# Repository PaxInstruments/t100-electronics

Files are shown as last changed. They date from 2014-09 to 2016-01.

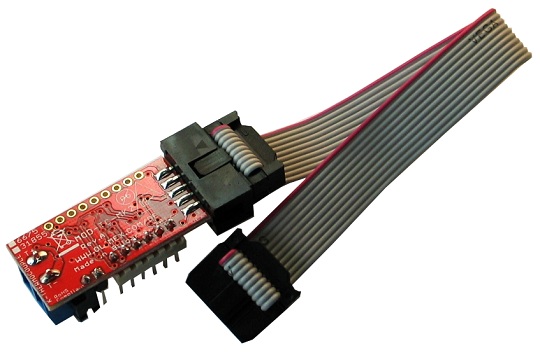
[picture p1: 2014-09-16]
referenceDesigns/Olimex-MOD-TC-MK2-31855-2-photoback.jpg

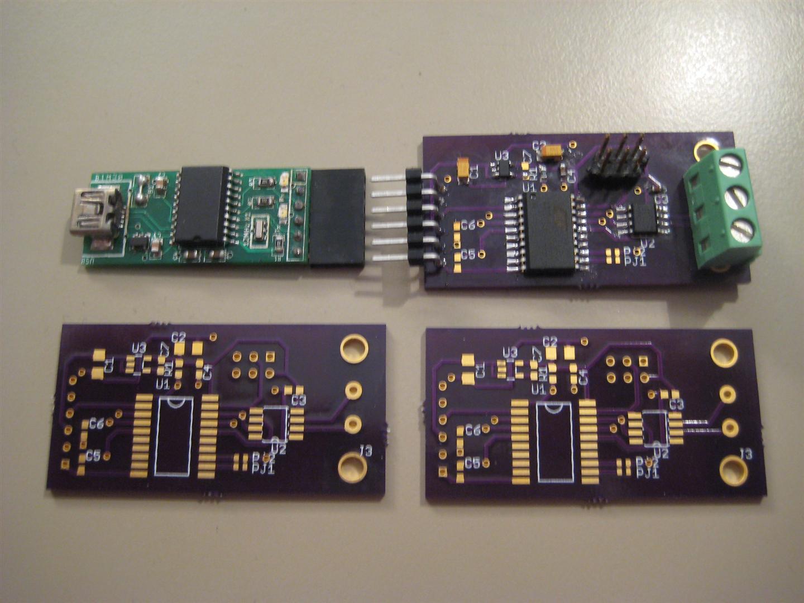
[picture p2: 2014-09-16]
referenceDesigns/SerialCouple-photo.JPG

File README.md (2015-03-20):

# t100-electronics

### Overview
Pax Instruments T100 thermocouple USB adapter.

## T100 Projects

- [Electronics](https://github.com/PaxInstruments/t100-electronics)
- [Enclosure](https://github.com/PaxInstruments/t100-enclosure)
- [Firmware](https://github.com/PaxInstruments/t100-firmware)
- [Software](https://github.com/PaxInstruments/t100-software)

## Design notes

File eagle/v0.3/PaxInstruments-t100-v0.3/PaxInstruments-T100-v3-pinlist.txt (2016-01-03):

Pinlist

Exported from PaxInstruments-T100.brd at 2016-01-03 10:57 

EAGLE Version 6.5.0 Copyright (c) 1988-2013 CadSoft

Part     Pad      Net

C1       1        USB_5V
         2        GND

C2       1        A_5V
         2        AGND

C4       1        A_5V
         2        AGND

C5       1        A_5V
         2        AGND

C6       1        TC-
         2        AGND

C7       1        TC+
         2        AGND

C8       1        TC+
         2        TC-

C9       1        USB_5V
         2        GND

D1       1        N$2
         2        GND

D2       1        N$1
         2        GND

JP2      1        SPARE
         2        USB_5V
         3        SCL
         4        SDA
         5        /RST
         6        GND

JP3      1        GND
         2        SPARE

JP4      D+1      N$1
         D-1      N$2
         GND1     USB_5V
         P$1               *** unconnected ***
         P$3               *** unconnected ***
         VBUS1    GND

LED1     A        N$5
         C        GND

R1       1        D+
         2        N$2

R2       1        D-
         2        N$1

R3       1        AGND
         2        N$3

R4       1        N$4
         2        A_5V

R5       1        TC-
         2        N$3

R6       1        TC+
         2        N$4

R7       1        SDA
         2        USB_5V

R8       1        SCL
         2        USB_5V

R9       1        N$1
         2        USB_5V

R10      1        N$5
         2        SPARE

SJ1      1        A_5V
         2        USB_5V

SJ2      1        GND
         2        AGND

U$1     
U$2      P$1      N$3

U$3      1        TC+
         2        AGND
         3        SCL
         4        SDA
         5        A_5V
         6        TC-

U$4      1        A_5V
         2        AGND
         3                 *** unconnected ***
         4        SCL
         5        SDA

U$6      P$1      N$4

U1       1        /RST
         2        D-
         3        D+
         4        GND
         5        SDA
         6        SPARE
         7        SCL
         8        USB_5V

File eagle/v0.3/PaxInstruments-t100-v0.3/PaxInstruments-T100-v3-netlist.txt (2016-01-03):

Netlist

Exported from PaxInstruments-T100.brd at 2016-01-03 10:57 

EAGLE Version 6.5.0 Copyright (c) 1988-2013 CadSoft

Net      Part     Pad

/RST     JP2      5
         U1       1

AGND     C2       2
         C4       2
         C5       2
         C6       2
         C7       2
         R3       1
         SJ2      2
         U$3      2
         U$4      2

A_5V     C2       1
         C4       1
         C5       1
         R4       2
         SJ1      1
         U$3      5
         U$4      1

D+       R1       1
         U1       3

D-       R2       1
         U1       2

GND      C1       2
         C9       2
         D1       2
         D2       2
         JP2      6
         JP3      1
         JP4      VBUS1
         LED1     C
         SJ2      1
         U1       4

N$1      D2       1
         JP4      D+1
         R2       2
         R9       1

N$2      D1       1
         JP4      D-1
         R1       2

N$3      R3       2
         R5       2
         U$2      P$1

N$4      R4       1
         R6       2
         U$6      P$1

N$5      LED1     A
         R10      1

SCL      JP2      3
         R8       1
         U$3      3
         U$4      4
         U1       7

SDA      JP2      4
         R7       1
         U$3      4
         U$4      5
         U1       5

SPARE    JP2      1
         JP3      2
         R10      2
         U1       6

TC+      C7       1
         C8       1
         R6       1
         U$3      1

TC-      C6       1
         C8       2
         R5       1
         U$3      6

USB_5V   C1       1
         C9       1
         JP2      2
         JP4      GND1
         R7       2
         R8       2
         R9       2
         SJ1      2
         U1       8

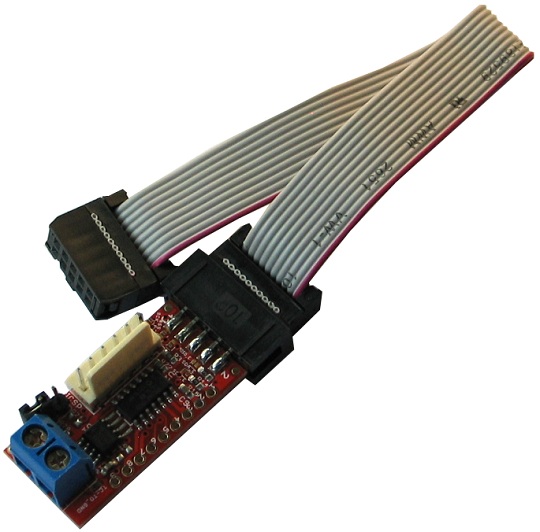
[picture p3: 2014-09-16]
referenceDesigns/Olimex-MOD-TC-MK2-photo-front.jpg

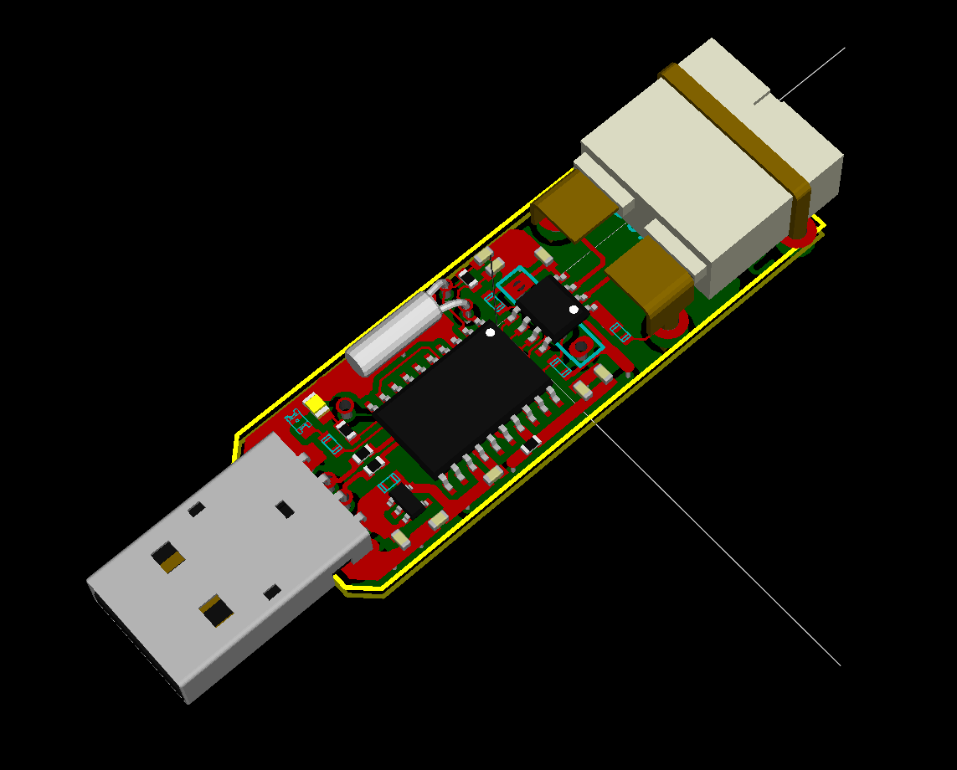
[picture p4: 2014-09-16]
referenceDesigns/GGLabs-ustk01-render.png

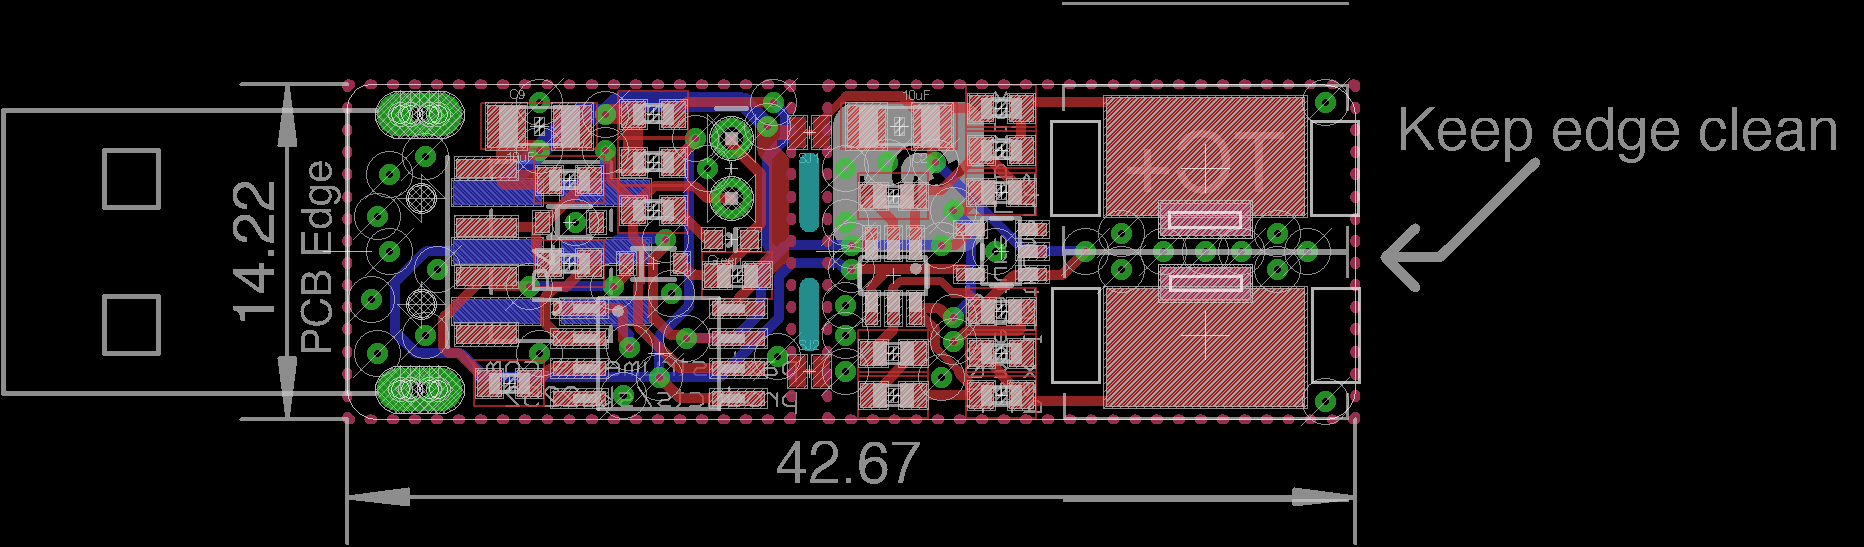
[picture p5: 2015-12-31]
eagle/v0.3/PaxInstruments-t100-v0.3/PaxInstruments-T100-v3-pcb.png

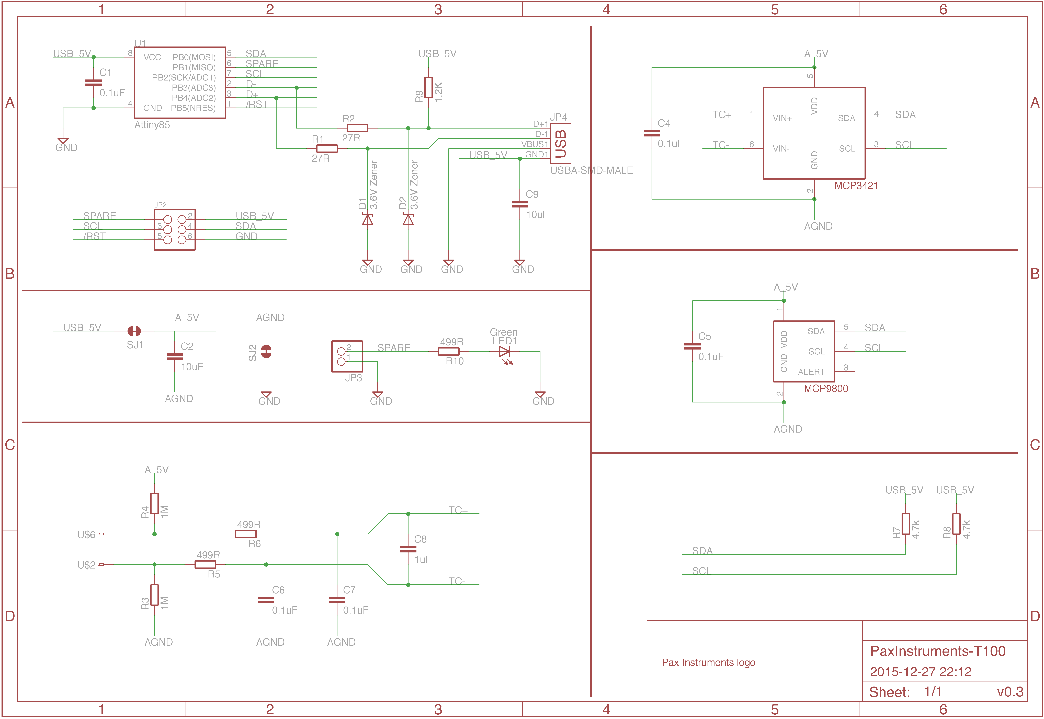
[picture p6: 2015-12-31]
eagle/v0.3/PaxInstruments-t100-v0.3/PaxInstruments-T100-v3-sch.png

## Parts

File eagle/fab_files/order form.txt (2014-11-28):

Board size (板子大小)
45 x 18 mm

Board layers (板子层数)
2

Board quantity (板子数量)
10

Board thickness (板子厚度)
1.6 mm

Minimum line width/spacing (最小线宽/线距)
6/6

Via (过孔)
0.3 mm

Solder mask color (阻焊颜色)
Blue (蓝色)

Character color (字符颜色)
White (白色)

Pad spraying (焊盘喷镀)
Immersion Gold (沉金)

Solder coverage (阻焊覆盖)
Through-hole cover oil (过孔盖油)

Flying probe test (飞针测试)
Visual (目测)

Copper thickness (铜箔厚度)
1 oz

Delivery time (发货时间)
48 hour expedited service (48小时加急服务)

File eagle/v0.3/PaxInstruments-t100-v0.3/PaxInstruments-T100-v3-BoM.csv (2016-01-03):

Qty | Value | Device | Package | Parts | Description | MF | MPN | OC_DIGIKEY | POPULATE | PROD_ID | TOLERANCE | VALUE
5 | 0.1uF | C-EUC0603 | C0603 | C1, C4, C5, C6, C7 | CAPACITOR, European symbol | Yageo | CC0603JRX7R9BB104 | 311-1779-2-ND | generic |  | 5%
1 | 1.2K | R-EU_R0603 | R0603 | R9 | RESISTOR, European symbol | Yageo | RC0603JR-071K2L | 311-1.2KGRTR-ND | generic |  | 5%
2 | 10uF | CAP1206 | 1206 | C2, C9 | Capacitor | Yageo | CC1206KKX5R7BB106 | 311-1465-2-ND | generic |  | 10%
2 | 1M | R-EU_R0603 | R0603 | R3, R4 | RESISTOR, European symbol | Yageo | RC0603FR-071ML | 311-1.00MHRTR-ND | generic |  | 1%
1 | 1uF | C-EUC0603 | C0603 | C8 | CAPACITOR, European symbol | Murata Electronics North America | GRM155R60J105KE19D | 490-1320-2-ND | generic |  | 10%
2 | 27R | R-EU_R0603 | R0603 | R1, R2 | RESISTOR, European symbol | Yageo | RC0603JR-0727RL | 311-27GRTR-ND | generic |  | 5%
2 | 3.6V Zener | DIODE-ZENER-BZT52 | SOD-323 | D1, D2 | Zener Diode | Diodes Incorporated | BZT52C3V6S-7-F | BZT52C3V6S-FDITR-ND | generic
2 | 4.7k | R-EU_R0603 | R0603 | R7, R8 | RESISTOR, European symbol | Yageo | RC0603JR-074K7L | 311-4.7KGRTR-ND | generic |  | 5%
3 | 499R | R-EU_R0603 | R0603 | R5, R6, R10 | RESISTOR, European symbol | Yageo | RT0603DRD07499RL | 311-499DTR-ND | generic |  | 0.5%
1 | Attiny85 | ATTINY45TINY45-20-SMT | SO08-EIAJ | U1 | Atmel 8-pin 2/4/8kB flash uC | Atmel | ATTINY85-20SUR | ATTINY85-20SURTR-ND | MPN | IC-08922 |  | Tiny45-20-SMT
1 | Green | LED0603 | LED-0603 | LED1 | LEDs | Lite-On Inc. | LTST-C191KGKT | 160-1446-2-ND | generic
1 | MCP3421A0 | MCP3421 | SOT23-6 | U$3 |  | Microchip Technology | MCP3421A0T-E/CH | MCP3421A0T-E/CHTR-ND | MPN
1 | MCP9800A0 | MCP9800 | SOT23-5 | U$4 |  | Microchip Technology | MCP9800A0T-M/OT | MCP9800A0T-M/OTTR-ND | MPN
1 | USBA-SMD-MALE | USBA-SMD-MALE | USB-A-SMT-MALE | JP4 | USB-A with SMT pads |  |  |  | generic

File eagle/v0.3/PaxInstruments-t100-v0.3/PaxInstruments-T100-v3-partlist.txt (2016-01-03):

Partlist

Exported from PaxInstruments-T100.brd at 2016-01-03 10:57 

EAGLE Version 6.5.0 Copyright (c) 1988-2013 CadSoft

Assembly variant: 

Part     Value                           Package                          Library                   Position (mil)        Orientation

C1       0.1uF                           C0603                            rcl                       (650 260)             R180
C2       10uF                            1206                             SparkFun-Passives         (920 510)             R180
C4       0.1uF                           C0603                            rcl                       (910 130)             R0
C5       0.1uF                           C0603                            rcl                       (1090 200)            R0
C6       0.1uF                           C0603                            rcl                       (910 60)              R180
C7       0.1uF                           C0603                            rcl                       (910 392.5)           R180
C8       1uF                             C0603                            rcl                       (1090 400)            R180
C9       10uF                            1206                             SparkFun-Passives         (320 510)             R0
D1       3.6V Zener                      SOD-323                          SparkFun-DiscreteSemi     (510 280)             R0
D2       3.6V Zener                      SOD-323                          SparkFun-DiscreteSemi     (370 350)             R0
JP2                                      2X3_SMT_POSTS                    SparkFun-Connectors       (340 300)             MR270
JP3                                      1X02_ROUND                       microbuilder              (640 440)             R270
JP4      USBA-SMD-MALE                   USB-A-SMT-MALE                   SparkFun-Connectors       (0 300)               R90
LED1     Green                           LED-0603                         SparkFun-LED              (640 320)             R270
R1       27R                             R0603                            rcl                       (270 80)              R180
R2       27R                             R0603                            rcl                       (370 280)             R180
R3       1M                              R0603                            rcl                       (1090 130)            R180
R4       1M                              R0603                            rcl                       (1090 540)            R180
R5       499R                            R0603                            rcl                       (1090 60)             R0
R6       499R                            R0603                            rcl                       (1090 470)            R0
R7       4.7k                            R0603                            rcl                       (510 450)             R180
R8       4.7k                            R0603                            rcl                       (510 530)             R180
R9       1.2K                            R0603                            rcl                       (370 420)             R180
R10      499R                            R0603                            rcl                       (510 370)             R180
SJ1      JUMPER-PAD-2-NC_BY_TRACENO_SILK PAD-JUMPER-2-NC_BY_TRACE_NO_SILK SparkFun-Passives         (770 500)             R180
SJ2      JUMPER-PAD-2-NC_BY_TRACENO_SILK PAD-JUMPER-2-NC_BY_TRACE_NO_SILK SparkFun-Passives         (770 100)             R0
U$2      TC-MINI-SINGLE                  TC-CLIP-SINGLE                   PaxInstruments-Connectors (1430 160)            R90
U$3      MCP3421A0                       SOT23-6                          SparkFun-DigitalIC        (910 260)             R180
U$4      MCP9800A0                       SOT23-5                          SparkFun-DigitalIC        (1090 300)            R90
U$6      TC-MINI-SINGLE                  TC-CLIP-SINGLE                   PaxInstruments-Connectors (1430 440)            R270
U1       Attiny85                        SO08-EIAJ                        SparkFun-DigitalIC_ihsan  (520 130)             R270

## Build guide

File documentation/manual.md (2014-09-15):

t100-electronics
================

A single thermocouple to USB adapter.

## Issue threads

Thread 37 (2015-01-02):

BoM in schematic

charlespax, 2015-01-02:
Each part in the schematic should have attributes for part numbers.

As an example this screenshot for version 0.9 of the T400 shows the MCP9800 with its attribute window open.
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

MPM - Manufacturer part number
OC_DIGIKEY - Order code for Digikey
OC_MOUSER - Order code for Mouser

charlespax, 2015-10-05:
Done in tag t100-0.3

Closed 2015-10-05.

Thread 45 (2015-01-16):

Temperature differential

charlespax, 2015-01-16:
In a test comparing a T100 prototype with a Fluke 54B thermocouple device, there was a discrepancy between the two readings. This may have been due to an inaccuracy in measuring the true junction temperature. The experiment should be repeated under better thermal conditions to determine if there there is a hardware problem that needs to be fixed.

The test: https://github.com/PaxInstruments/t100-electronics/issues/41

charlespax, 2015-10-05:
Doesn't look like a headwear issue. Just a difference in the thermocouples used. Closing

Closed 2015-10-05.

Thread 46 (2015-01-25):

Grounding the itothermal plane

charlespax, 2015-01-25:
There has been a bit of research into how we should ground the isothermal plane on the T400. This has implications for the T100 also. It looks like we shouldn't be using an inductor, but a "zero ohm resistor." See https://github.com/PaxInstruments/t400-electronics/issues/59 and https://github.com/PaxInstruments/t400-electronics/issues/123

charlespax, 2015-09-25:
@kehribar this can be closed, right?

```
commit 1bf0f2758d1781c4f25094f72275e58422c0bae4
Author: kehribar <ihsan@kehribar.me>
Date:   Tue Aug 25 20:27:17 2015 +0300

    New library added. Inductor changed to resistor. Logo placement.
```

Closed 2015-09-25.

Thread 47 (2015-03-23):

MCP9800 part number

charlespax, 2015-03-23:
Please specify part MCP9800A0 in the schematic. We support both MCP9800A0 and MCP9800A5 (https://github.com/PaxInstruments/t100-firmware/issues/9). However, the choice should be clear to the factory.

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

Closed 2015-09-25.

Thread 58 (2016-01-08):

Key slots

charlespax, 2016-01-08:
On the production PCBs the keyway slots a a bit too small for the keys on the enclosure. We have to rework these slots by hand in the first batch. Revise files in next batch.

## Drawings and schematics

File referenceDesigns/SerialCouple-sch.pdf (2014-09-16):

### ABCDE

### ABCDE

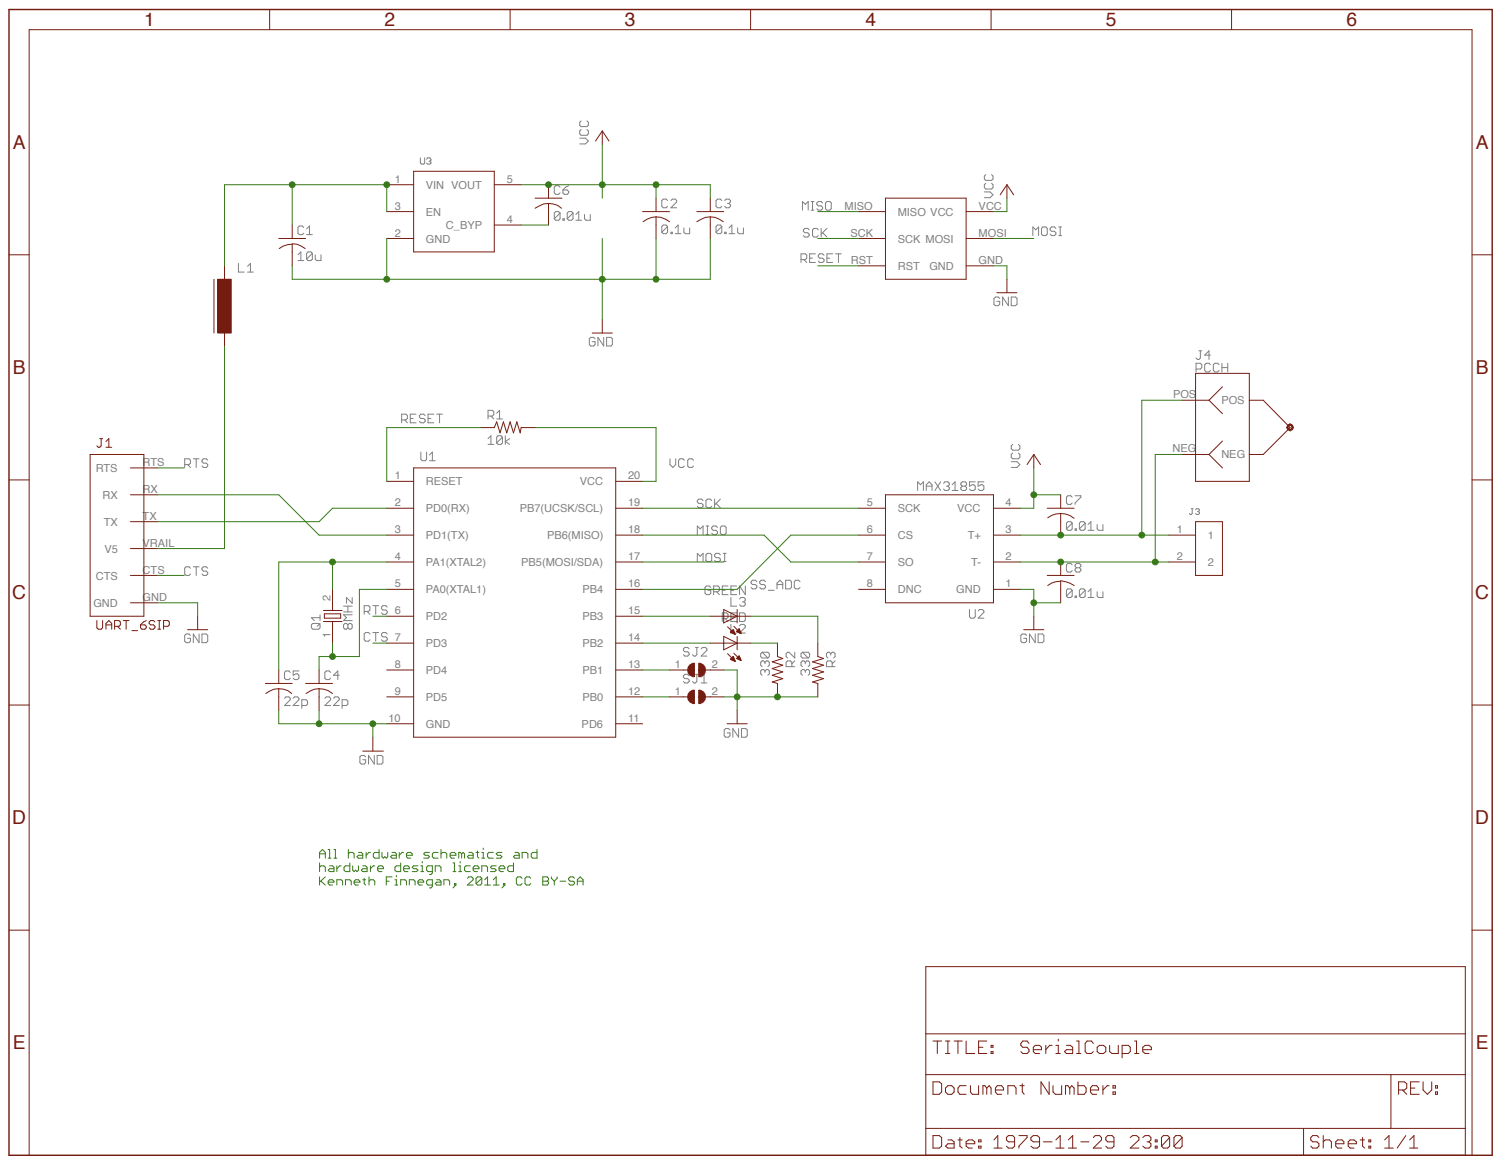
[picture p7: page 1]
RESET; PA1(XTAL2); PA0(XTAL1); GND 10; PB5(MOSI/SDA); PB6(MISO); PB7(UCSK/SCL); VCC; GND; 4 SCK; DNC; VIN; C_BYP; VOUT; MISO MISO; SCK SCK; RST RST; MOSI; RTS; VRAIL; CTS; POS POS; NEG NEG

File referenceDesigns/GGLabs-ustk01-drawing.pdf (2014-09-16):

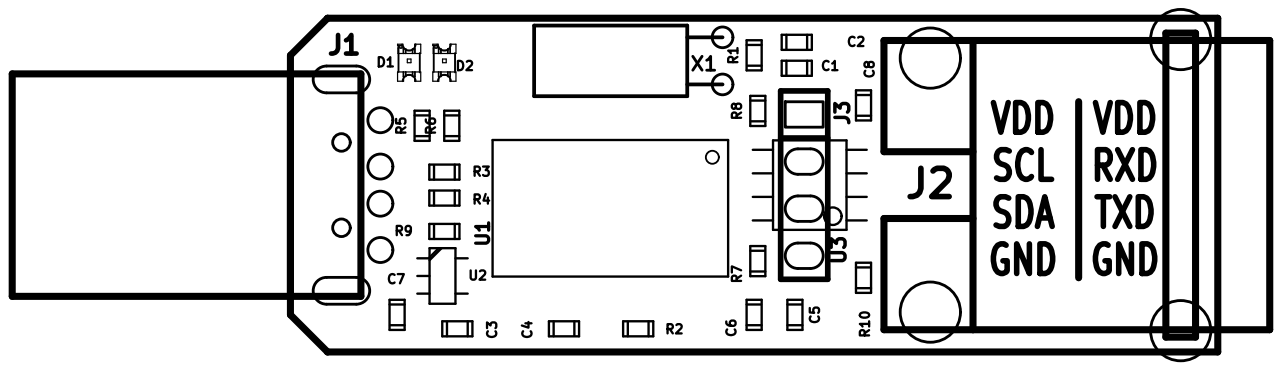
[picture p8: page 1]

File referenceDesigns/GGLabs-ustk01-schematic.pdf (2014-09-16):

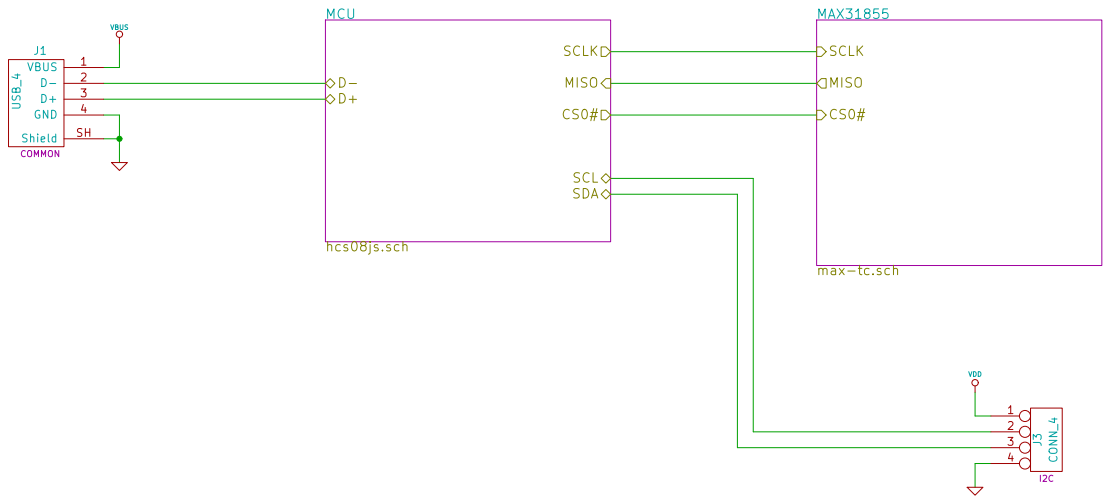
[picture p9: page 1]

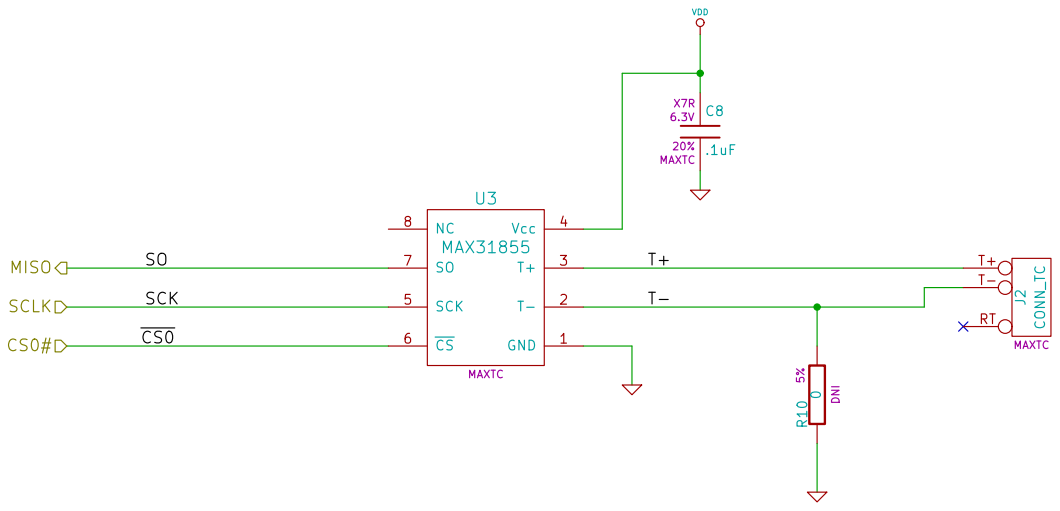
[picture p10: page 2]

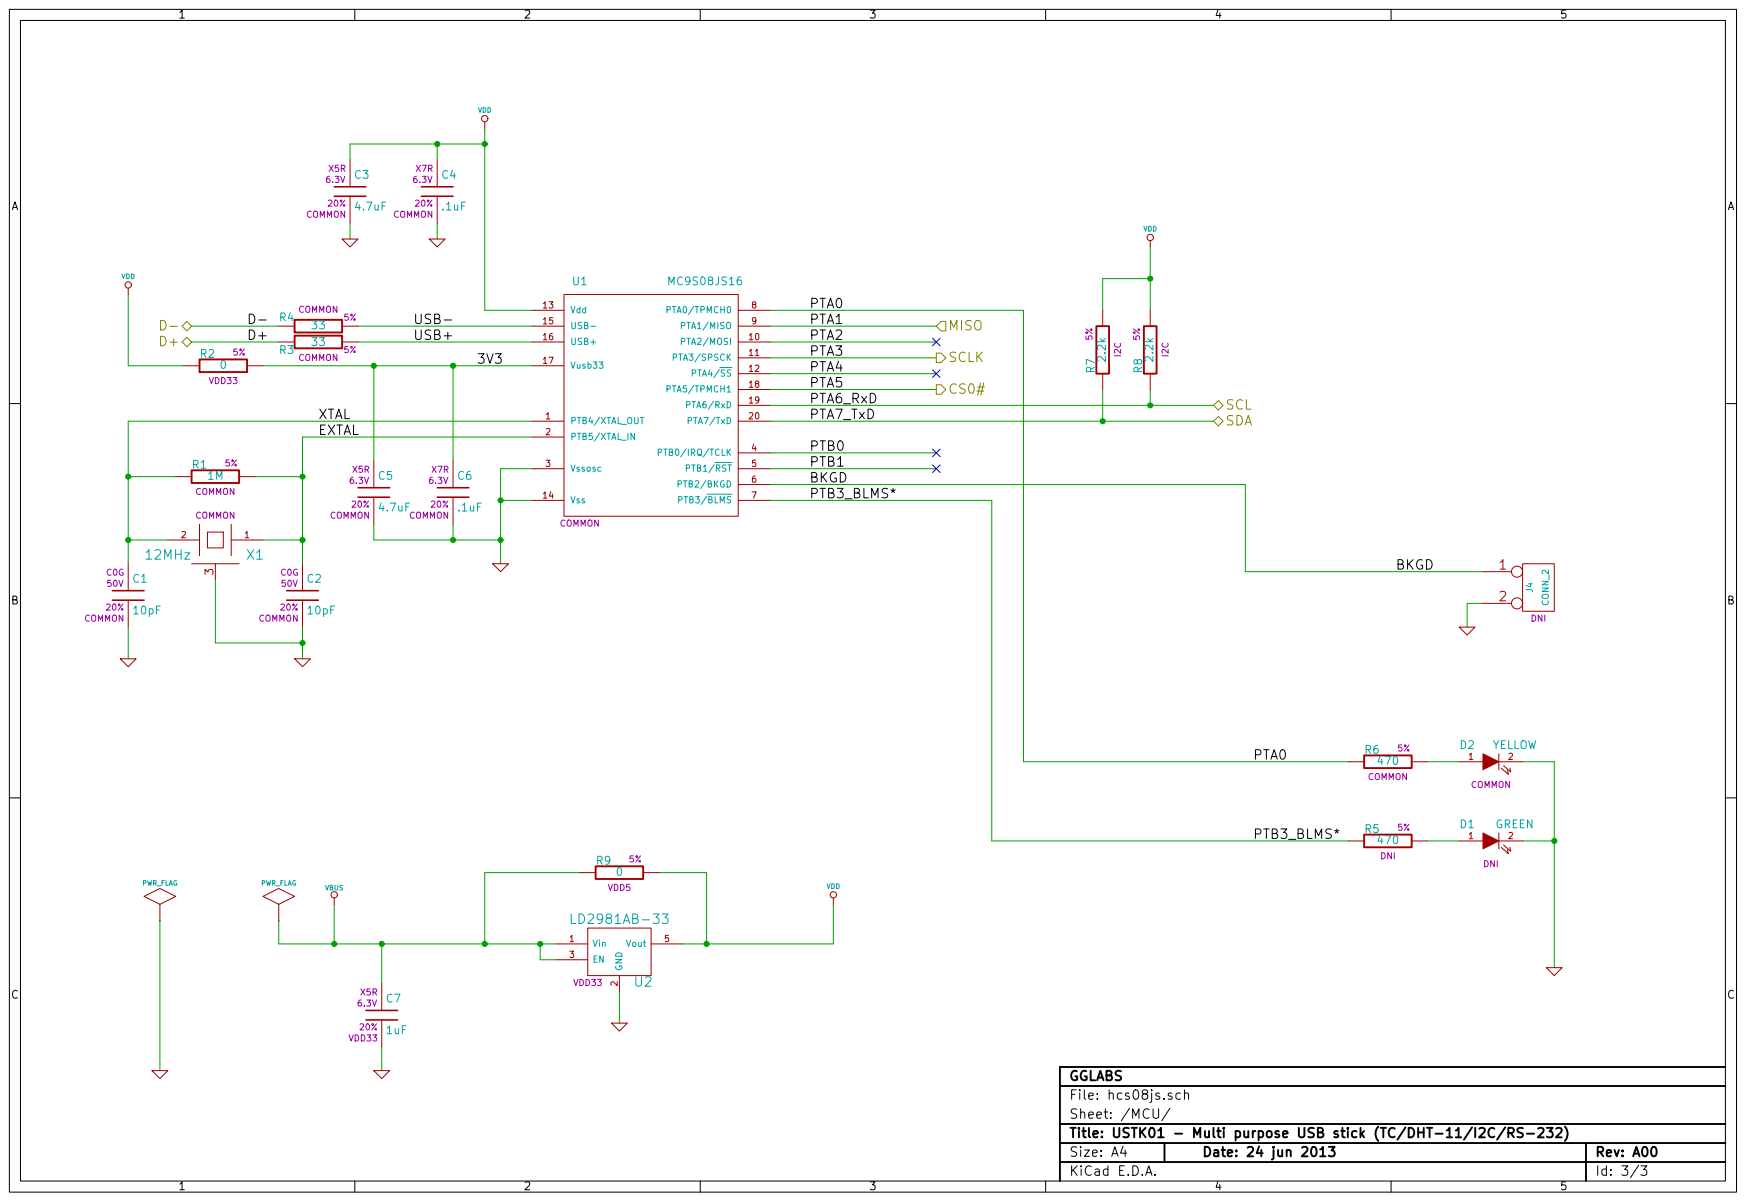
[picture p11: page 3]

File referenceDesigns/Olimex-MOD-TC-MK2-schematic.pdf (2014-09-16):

MCU | UEXTs

# GPIO

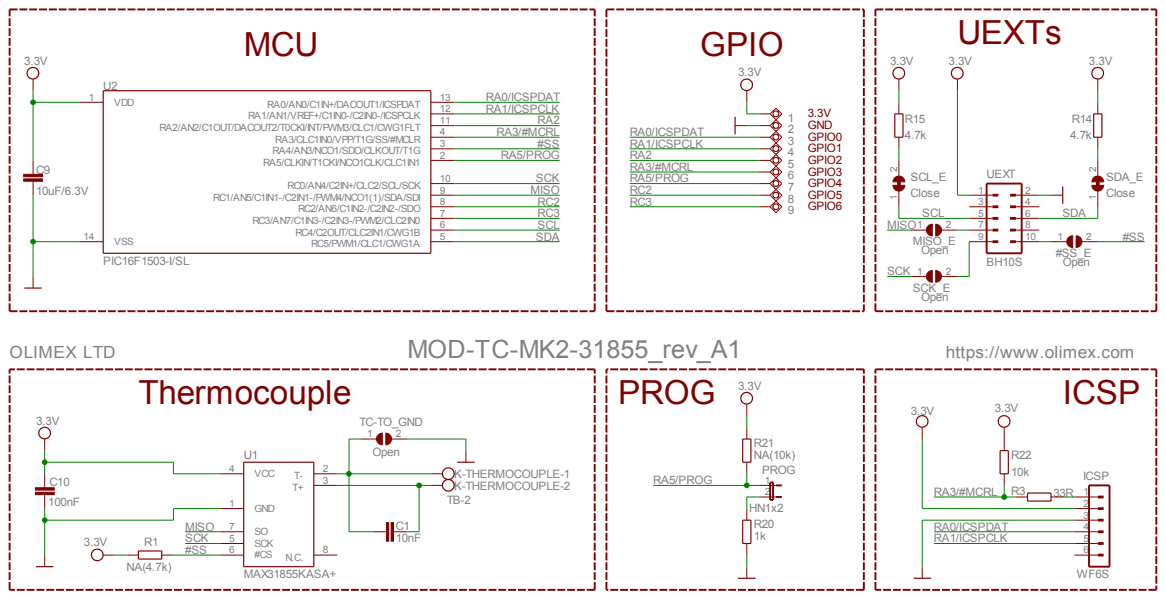
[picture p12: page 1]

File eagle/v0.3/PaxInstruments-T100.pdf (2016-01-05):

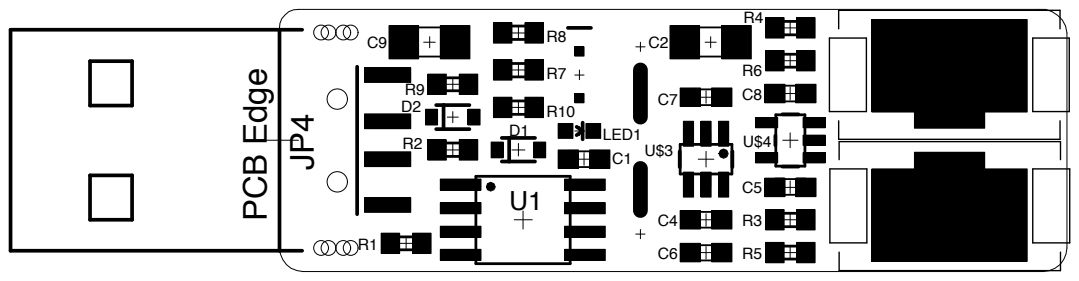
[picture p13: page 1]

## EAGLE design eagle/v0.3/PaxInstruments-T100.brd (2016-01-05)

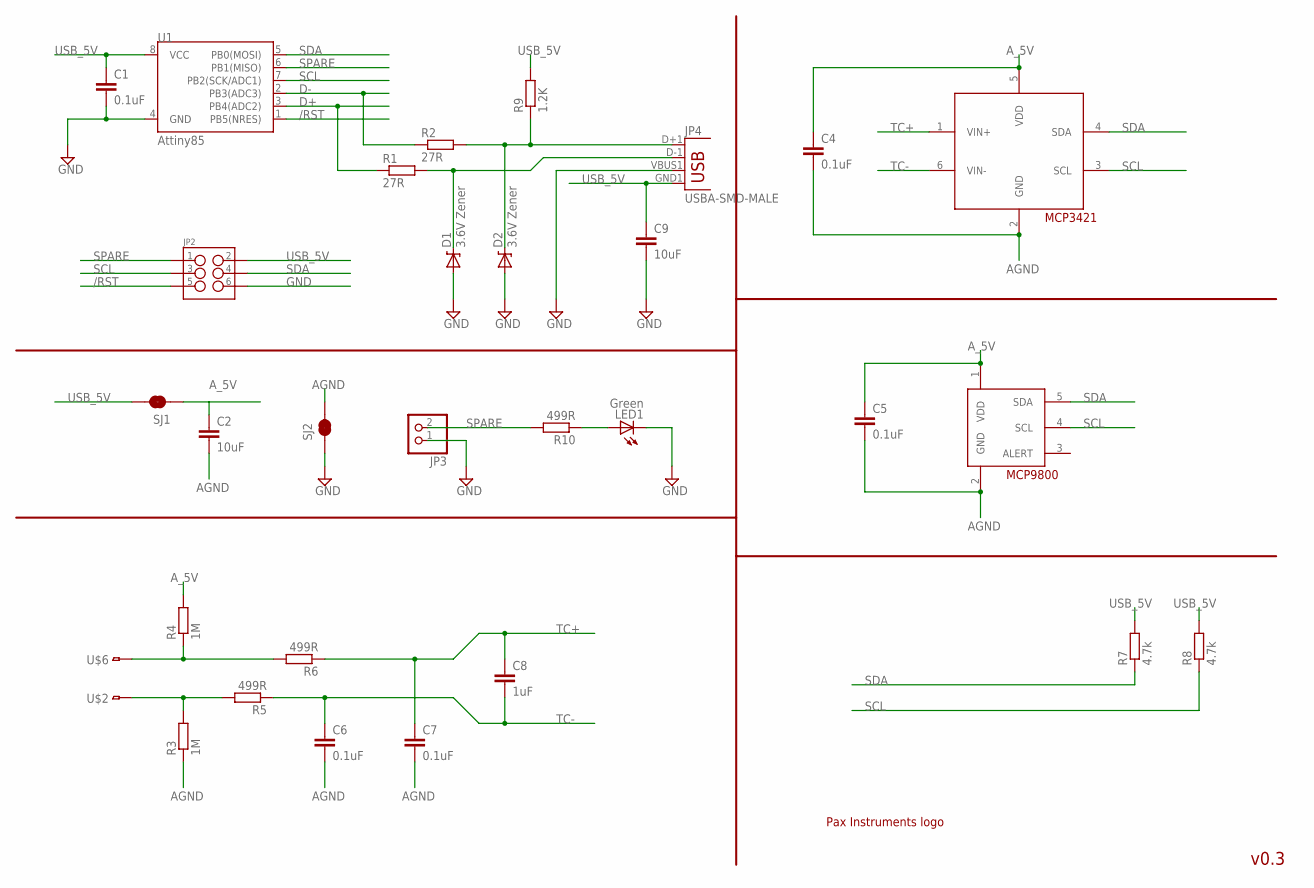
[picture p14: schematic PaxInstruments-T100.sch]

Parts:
C1, C4, C5, C6, C7: 0.1uF; C0603; TOLERANCE 5%; MPN CC0603JRX7R9BB104
C2, C9: 10uF; 1206; TOLERANCE 10%; MPN CC1206KKX5R7BB106
C8: 1uF; C0603; TOLERANCE 10%; MPN GRM155R60J105KE19D
D1, D2: 3.6V Zener; SOD-323; MPN BZT52C3V6S-7-F
JP2: M03X2SMT; 2X3_SMT_POSTS; MPN 95278-101A06LF
JP3: HEADER-1X2ROUND; 1X02_ROUND
JP4: USBA-SMD-MALE; USB-A-SMT-MALE
LED1: Green; LED-0603; MPN LTST-C191KGKT
R1, R2: 27R; R0603; TOLERANCE 5%; MPN RC0603JR-0727RL
R3, R4: 1M; R0603; TOLERANCE 1%; MPN RC0603FR-071ML
R5, R6, R10: 499R; R0603; TOLERANCE 0.5%; MPN RT0603DRD07499RL
R7, R8: 4.7k; R0603; TOLERANCE 5%; MPN RC0603JR-074K7L
R9: 1.2K; R0603; TOLERANCE 5%; MPN RC0603JR-071K2L
SJ1, SJ2: JUMPER-PAD-2-NC_BY_TRACENO_SILK; PAD-JUMPER-2-NC_BY_TRACE_NO_SILK
U1: Attiny85; SO08-EIAJ; MPN ATTINY85-20SUR
U$1: PAX-LOGOPAX-LOGO-0.25IN; PAX-LOGO-0.25IN
U$2, U$6: TC-MINI-SINGLE; TC-CLIP-SINGLE; MPN 1024
U$3: MCP3421A0; SOT23-6; MPN MCP3421A0T-E/CH
U$4: MCP9800A0; SOT23-5; MPN MCP9800A0T-M/OT

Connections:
/RST: JP2.5, U1.1 (PB5(NRES))
AGND: C2.2, C4.2, C5.2, C6.2, C7.2, R3.1, SJ2.2, U$3.2 (GND), U$4.2 (GND)
A_5V: C2.1, C4.1, C5.1, R4.2, SJ1.1, U$3.5 (VDD), U$4.1 (VDD)
D+: R1.1, U1.3 (PB4(ADC2))
D-: R2.1, U1.2 (PB3(ADC3))
GND: C1.2, C9.2, D1.2 (A), D2.2 (A), JP2.6, JP3.1, JP4.VBUS1 (VBUS), LED1.C, SJ2.1, U1.4 (GND)
unnamed: D2.1 (C), JP4.D+1 (D+), R2.2, R9.1
unnamed: D1.1 (C), JP4.D-1 (D-), R1.2
unnamed: R3.2, R5.2, U$2.P$1
unnamed: R4.1, R6.2, U$6.P$1
unnamed: LED1.A, R10.1
SCL: JP2.3, R8.1, U1.7 (PB2(SCK/ADC1)), U$3.3 (SCL), U$4.4 (SCL)
SDA: JP2.4, R7.1, U1.5 (PB0(MOSI)), U$3.4 (SDA), U$4.5 (SDA)
SPARE: JP2.1, JP3.2, R10.2, U1.6 (PB1(MISO))
TC+: C7.1, C8.1, R6.1, U$3.1 (VIN+)
TC-: C6.1, C8.2, R5.1, U$3.6 (VIN-)
USB_5V: C1.1, C9.1, JP2.2, JP4.GND1 (GND), R7.2, R8.2, R9.2, SJ1.2, U1.8 (VCC)

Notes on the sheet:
v0.3

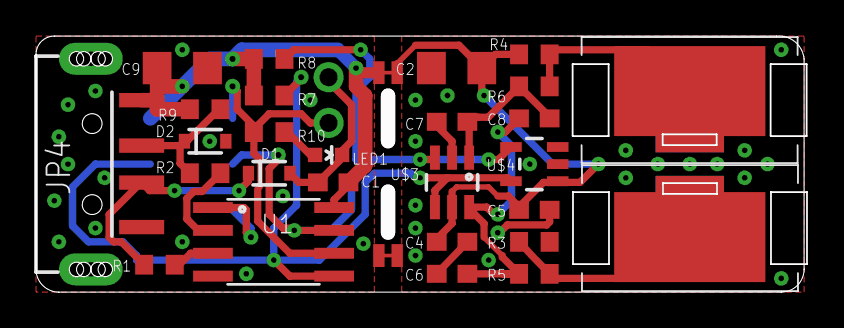
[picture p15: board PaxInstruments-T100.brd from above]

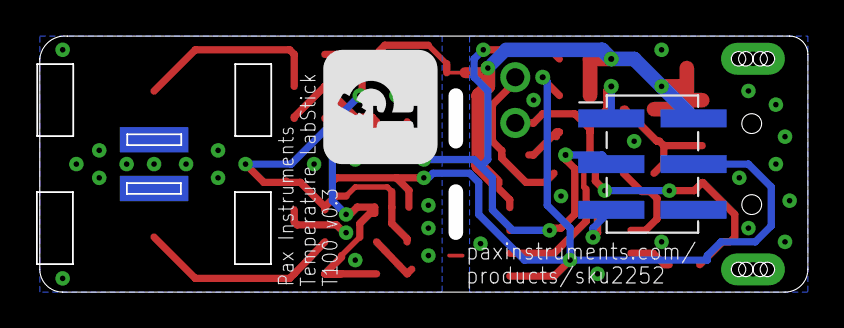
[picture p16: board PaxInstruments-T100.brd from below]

Board: 2 copper layers, 42.7 x 14.2 mm, 32 parts (2 on the bottom side), 17 nets.

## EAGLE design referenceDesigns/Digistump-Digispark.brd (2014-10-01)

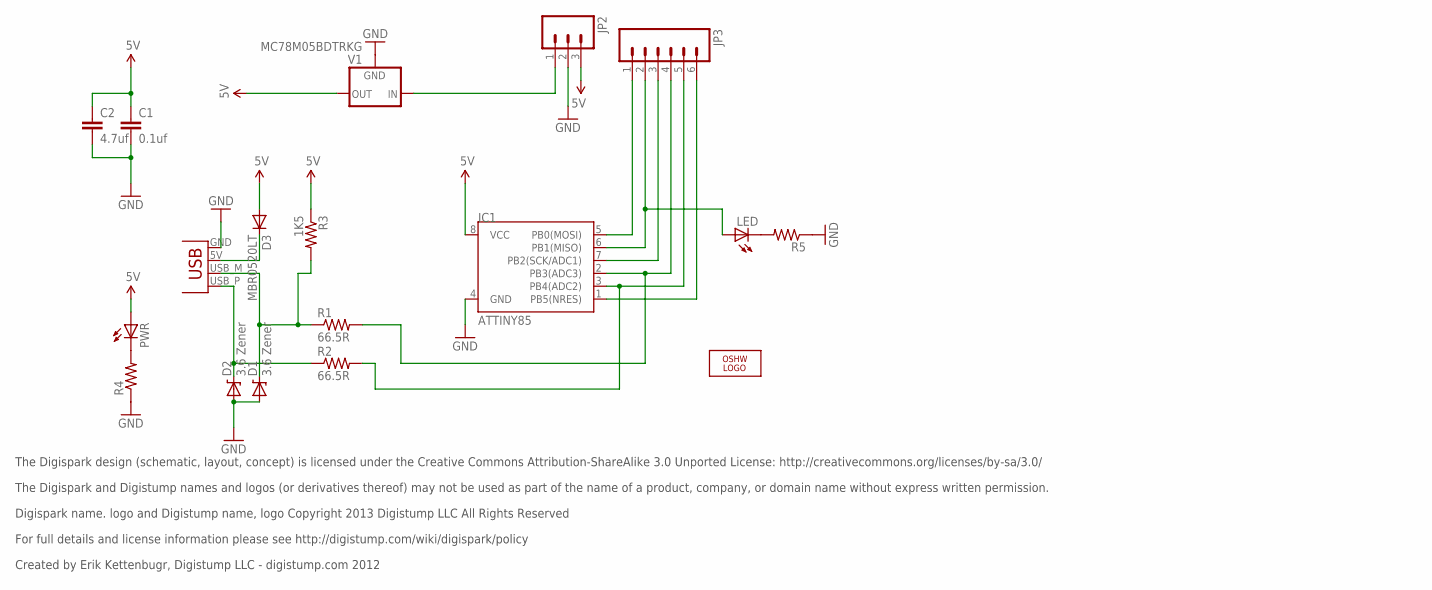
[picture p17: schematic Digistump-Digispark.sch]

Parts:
C1: 0.1uf; 0402-CAP
C2: 4.7uf; 0805
D1, D2: 3.6 Zener; SOD-323
D3: MBR0520LT; SOD123
IC1: ATTINY85; SO08-EIAJ
JP2: M03PTH; 1X03
JP3: M06SIP; 1X06
LED: LED0603; LED-0603
LOGO2: LOGO-OSHW-10MILX0200-NT; OSHW_10X200_NOTEXT
PWR: LED0603; LED-0603
R1, R2: 66.5R; 0402-RES
R3: 1K5; 0402-RES
R4, R5: RESISTOR0402-RES; 0402-RES
V1: MC78M05BDTRKG; DPACK
X1: USBPCB; USB-A-PCB

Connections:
5V: C1.1, C2.1, D3.A, IC1.8 (VCC), JP2.3, PWR.A, R3.1, V1.3 (OUT)
GND: C1.2, C2.2, D1.2 (A), D2.2 (A), IC1.4 (GND), JP2.2, R4.1, R5.1, V1.4 (GND), X1.GND
unnamed: IC1.2 (PB3(ADC3)), JP3.4, R1.2
unnamed: IC1.6 (PB1(MISO)), JP3.2, LED.A
unnamed: IC1.5 (PB0(MOSI)), JP3.1
unnamed: IC1.7 (PB2(SCK/ADC1)), JP3.3
unnamed: IC1.3 (PB4(ADC2)), JP3.5, R2.2
unnamed: IC1.1 (PB5(NRES)), JP3.6
unnamed: D1.1 (C), R1.1, R3.2, X1.USB_M (D-)
unnamed: D2.1 (C), R2.1, X1.USB_P (D+)
unnamed: LED.C, R5.2
unnamed: JP2.1, V1.1 (IN)
unnamed: D3.C, X1.5V (VBUS)
unnamed: PWR.C, R4.2

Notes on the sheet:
The Digispark design (schematic, layout, concept) is licensed under the Creative Commons Attribution-ShareAlike 3.0 Unported License: http://creativecommons.org/licenses/by-sa/3.0/
The Digispark and Digistump names and logos (or derivatives thereof) may not be used as part of the name of a product, company, or domain name without express written permission.
Digispark name. logo and Digistump name, logo Copyright 2013 Digistump LLC All Rights Reserved
For full details and license information please see http://digistump.com/wiki/digispark/policy
Created by Erik Kettenbugr, Digistump LLC - digistump.com 2012

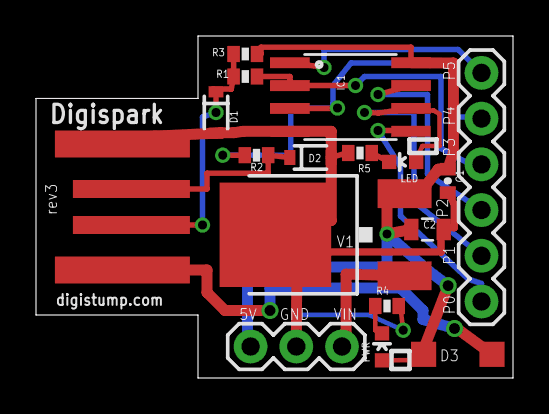
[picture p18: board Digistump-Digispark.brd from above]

Board: 2 copper layers, 26.5 x 19.0 mm, 18 parts (1 on the bottom side), 14 nets.

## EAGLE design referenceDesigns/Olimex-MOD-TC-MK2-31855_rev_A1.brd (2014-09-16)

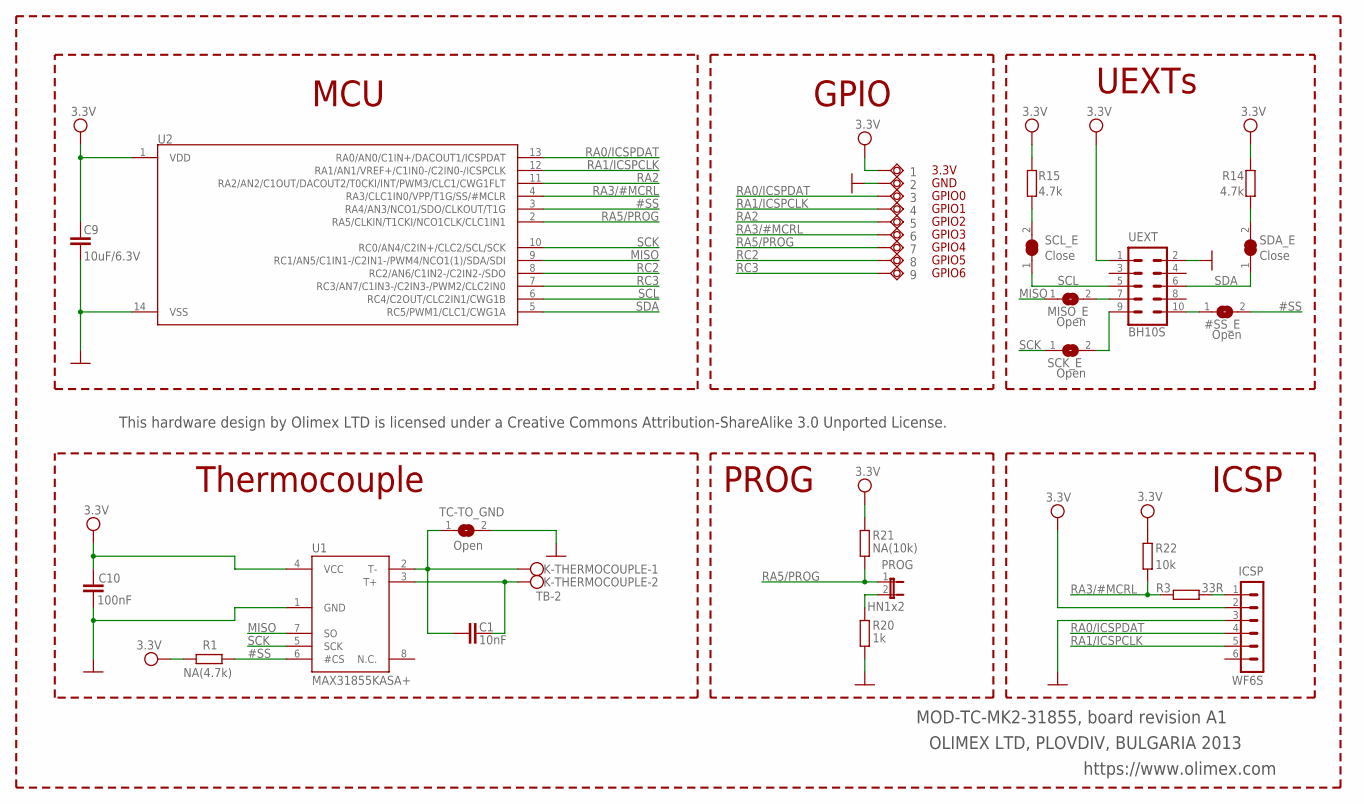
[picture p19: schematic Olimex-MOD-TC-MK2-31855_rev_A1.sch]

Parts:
1, 2, 3, 4, 5, 6, 7, 8, 9: TESTPAD40/70; TESTPAD
#SS_E: Open; SJ_1_SMALLER
C1: 10nF; C0603_5MIL
C9: 10uF/6.3V; C0603_5MIL
C10: 100nF; C0603_5MIL
ICSP: WF6S
K-THERMOCOUPLE: TB-2; AK500/2
MISO_E: Open; SJ_1_SMALLER
PROG: HN1x2; JP1
R1: NA(4.7k); R0603_5MIL
R3: 33R; R0603_5MIL
R14, R15: 4.7k; R0603_5MIL
R20: 1k; R0603_5MIL
R21: NA(10k); R0603_5MIL
R22: 10k; R0603_5MIL
SCK_E: Open; SJ_1_SMALLER
SCL_E: Close; SJ_1_SMALLER_CLOSE
SDA_E: Close; SJ_1_SMALLER_CLOSE
TC-TO_GND: Open; SJ_1_SMALLER
U1: MAX31855KASA+; SO-08
U2: PIC16F1503-I/SL; SOIC14
UEXT: BH10S; ML10_PADS

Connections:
#SS: #SS_E.2, R1.2, U1.6 (#CS), U2.3 (RA4/AN3/NCO1/SDO/CLKOUT/T1G)
GND: 2.P$1, C9.2, C10.2, ICSP.3, R20.1, TC-TO_GND.2, U1.1 (GND), U2.14 (VSS), UEXT.2
MISO: MISO_E.1, U1.7 (SO), U2.9 (RC1/AN5/C1IN1-/C2IN1-/PWM4/NCO1(1)/SDA/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)
unnamed: #SS_E.1, UEXT.10
unnamed: SCK_E.2, UEXT.9
unnamed: MISO_E.2, UEXT.7
unnamed: C1.1, K-THERMOCOUPLE.1, TC-TO_GND.1, U1.2 (T-)
unnamed: C1.2, K-THERMOCOUPLE.2, U1.3 (T+)
unnamed: ICSP.1, R3.1
unnamed: R14.1, SDA_E.2
unnamed: R15.1, SCL_E.2
unnamed: PROG.2, R20.2
RA0/ICSPDAT: 3.P$1, ICSP.4, U2.13 (RA0/AN0/C1IN+/DACOUT1/ICSPDAT)
RA1/ICSPCLK: 4.P$1, ICSP.5, U2.12 (RA1/AN1/VREF+/C1IN0-/C2IN0-/ICSPCLK)
RA2: 5.P$1, U2.11 (RA2/AN2/C1OUT/DACOUT2/T0CKI/INT/PWM3/CL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)
RA3/#MCRL: 6.P$1, R3.2, R22.2, U2.4 (RA3/CLC1IN0/VPP/T1G/SS/#MCLR)
RA5/PROG: 7.P$1, PROG.1, R21.1, U2.2 (RA5/CLKIN/T1CKI/NCO1CLK/CLC1IN1)
RC2: 8.P$1, U2.8 (RC2/AN6/C1IN2-/C2IN2-/SDO)
RC3: 9.P$1, U2.7 (RC3/AN7/C1IN3-/C2IN3-/PWM2/CLC2IN0)
SCK: SCK_E.1, U1.5 (SCK), U2.10 (RC0/AN4/C2IN+/CLC2/SCL/SCK)
SCL: SCL_E.1, U2.6 (RC4/C2OUT/CLC2IN1/CWG1B), UEXT.5
SDA: SDA_E.1, U2.5 (RC5/PWM1/CLC1/CWG1A), UEXT.6
VCC: 1.P$1, C9.1, C10.1, ICSP.2, R1.1, R14.2, R15.2, R21.2, R22.1, U1.4 (VCC), U2.1 (VDD), UEXT.1

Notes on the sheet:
ICSP
MCU
UEXTs
Thermocouple
GPIO4
GPIO5
GPIO6
GPIO1
GPIO2
GPIO3
GPIO0
GND
3.3V
GPIO
PROG
MOD-TC-MK2-31855, board revision A1
OLIMEX LTD, PLOVDIV, BULGARIA 2013
https://www.olimex.com
This hardware design by Olimex LTD is licensed under a Creative Commons Attribution-ShareAlike 3.0 Unported License.

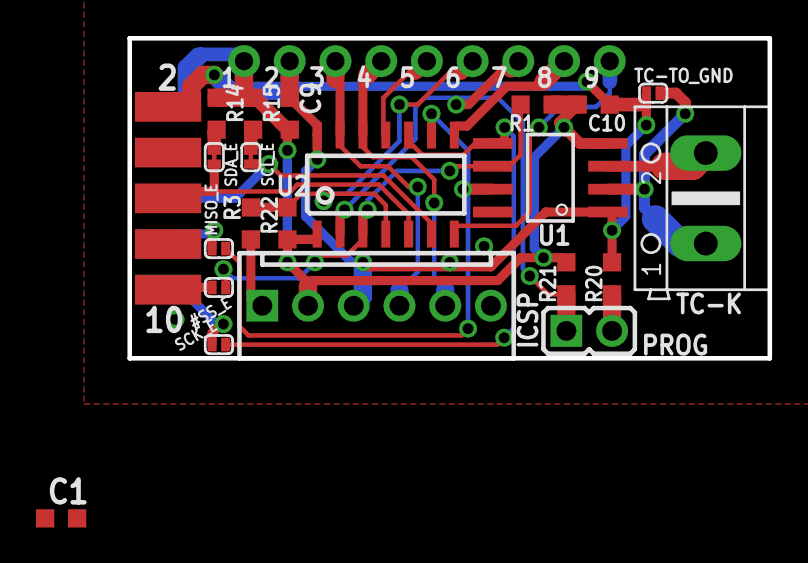
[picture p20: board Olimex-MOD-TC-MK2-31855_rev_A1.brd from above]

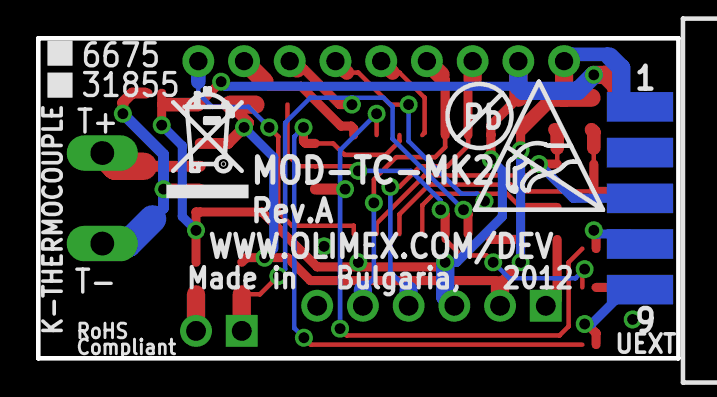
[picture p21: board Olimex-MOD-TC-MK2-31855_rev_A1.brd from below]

Board: 2 copper layers, 35.6 x 17.8 mm, 34 parts (4 on the bottom side), 23 nets.

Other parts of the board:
U$1: ESD_SYMBOL
U$6: RECYCLE_BIN1/8
U$7: PB_SMALL

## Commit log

2014-09-16 - added Olimex-MOD-TC-MK2 to referenceDesigns
    [Olimex-MOD-TC-MK2-31855_rev_A1.brd, Olimex-MOD-TC-MK2-31855_rev_A1.sch]
2014-09-16 - Added SerialCouple to referenceDesigns
    [SerialCouple.brd, SerialCouple.sch]
2014-10-01 - Added Digispark reference designs - Added USB-to-thermocouple data sheet
    [Digistump-Digispark.brd, Digistump-Digispark.sch]
2014-10-12 Initial schematic and mockup layout commit.
    [PaxInstruments-T100.brd, PaxInstruments-T100.sch]
2014-10-13 ISP connector is modified.
    [PaxInstruments-T100.brd, PaxInstruments-T100.sch]
2014-10-13 Layout changes with thermal cutout
    [PaxInstruments-T100.brd]
2014-11-12 Fixed clearance issues, added round corners and version number to the layout
    [PaxInstruments-T100.brd]
2015-01-01 TC connector is updated with the current one. Missing USB pullup resistor added
    [PaxInstruments-T100.brd, PaxInstruments-T100.sch]
2015-01-01 Date code and version number updated
    [PaxInstruments-T100.brd, PaxInstruments-T100.sch]
2015-02-23 Initial v0.3 design with isothermal plane connection changed to solder jumper.
    [PaxInstruments-T100.brd, PaxInstruments-T100.sch]
2015-02-23 Added indicator LED and breakout header.
    [PaxInstruments-T100.brd, PaxInstruments-T100.sch]
2015-08-24 [V0.3] - initial layout
    [PaxInstruments-T100.brd, PaxInstruments-T100.sch]
2015-08-25 New library added. Inductor changed to resistor. Logo placement.
    [PaxInstruments-T100.brd, PaxInstruments-T100.sch]
2015-08-25 Text label placements.
    [PaxInstruments-T100.brd, PaxInstruments-T100.sch]
2015-09-25 Added MCP9800A0 part number. Closes #47.
    [PaxInstruments-T100.brd, PaxInstruments-T100.sch]
2015-09-25 Added a bunch of BoM data.
    [PaxInstruments-T100.brd, PaxInstruments-T100.sch]
2015-09-25 Updated thermocoupel connector. Moved MCP9800 to between the thermocouple connectors. BoM should be finished.
    [PaxInstruments-T100.brd, PaxInstruments-T100.sch]
2015-09-26 Updated thermocouple connector with th emost recent version.
    [PaxInstruments-T100.brd, PaxInstruments-T100.sch]
2015-10-05 Made via holes smaller. Verified design. Ready to order PCBs. Added 0.3 fab files.
    [PaxInstruments-T100.brd, PaxInstruments-T100.sch, PaxInstruments-t100-v0.3-BoM.csv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]
2015-12-27 Changed USB connector. Updated thermocouple footprint. Rerouted board.
    [PaxInstruments-T100.brd, PaxInstruments-T100.sch]
2015-12-31 Ordering new 0.3 files.
    [PaxInstruments-T100-v0.3.BoM.csv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]
2016-01-03 Added fabrication files to v3.
    [PaxInstruments-T100-v0.3.BoM.csv, PaxInstruments-T100-v3-BoM.csv]
2016-01-05 Moved component names on PCB. Added location PDF.
    [PaxInstruments-T100.brd]

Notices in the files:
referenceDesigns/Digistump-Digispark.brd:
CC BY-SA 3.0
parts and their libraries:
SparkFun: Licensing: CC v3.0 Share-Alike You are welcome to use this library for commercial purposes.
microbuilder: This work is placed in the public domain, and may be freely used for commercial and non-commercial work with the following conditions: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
